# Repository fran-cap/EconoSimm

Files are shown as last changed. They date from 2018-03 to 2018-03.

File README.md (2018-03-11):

# EconoSimm
## A low cost Rom for SE/30 machines and compatables
Simply put this allows for a custom rom to be installed inside of a se/30 to skip things like the built in RAM check.
You can also use any extra space to fit in a small system file.

I've based this off of the work of [Doug Brown](https://www.downtowndougbrown.com/category/mac-rom-hacking/).
And GGlabs [MACSIMM](https://gglabs.us/node/2019).

You can find information about making a rom [here](http://www.bigmessowires.com/mac-rom-inator-ii/) (shoutouts to BMOW)
And how to make a custom disk image [here](http://www.bigmessowires.com/2016/07/22/rom-disk-creation-with-rom-inator-ii/).

The max size of any rom image will depend on the size of the flash chips you use but the max is 4 4mb chips or 2MB in total.
You can split any rom file you make into 4 pieces using the tool of your choice and burn that to each of the 4 chips.

## Note: The pcb has to be 1.2MM thick (approx) or it will not fit into a rom socket!

### You can program the chips individually with a standard flash programmer and a 32 PLCC -> dip adapter
BMOW's programmer may work but I have not tested it.

#### I'm not liable if this damages your Macintosh

## Replaces this:
rom

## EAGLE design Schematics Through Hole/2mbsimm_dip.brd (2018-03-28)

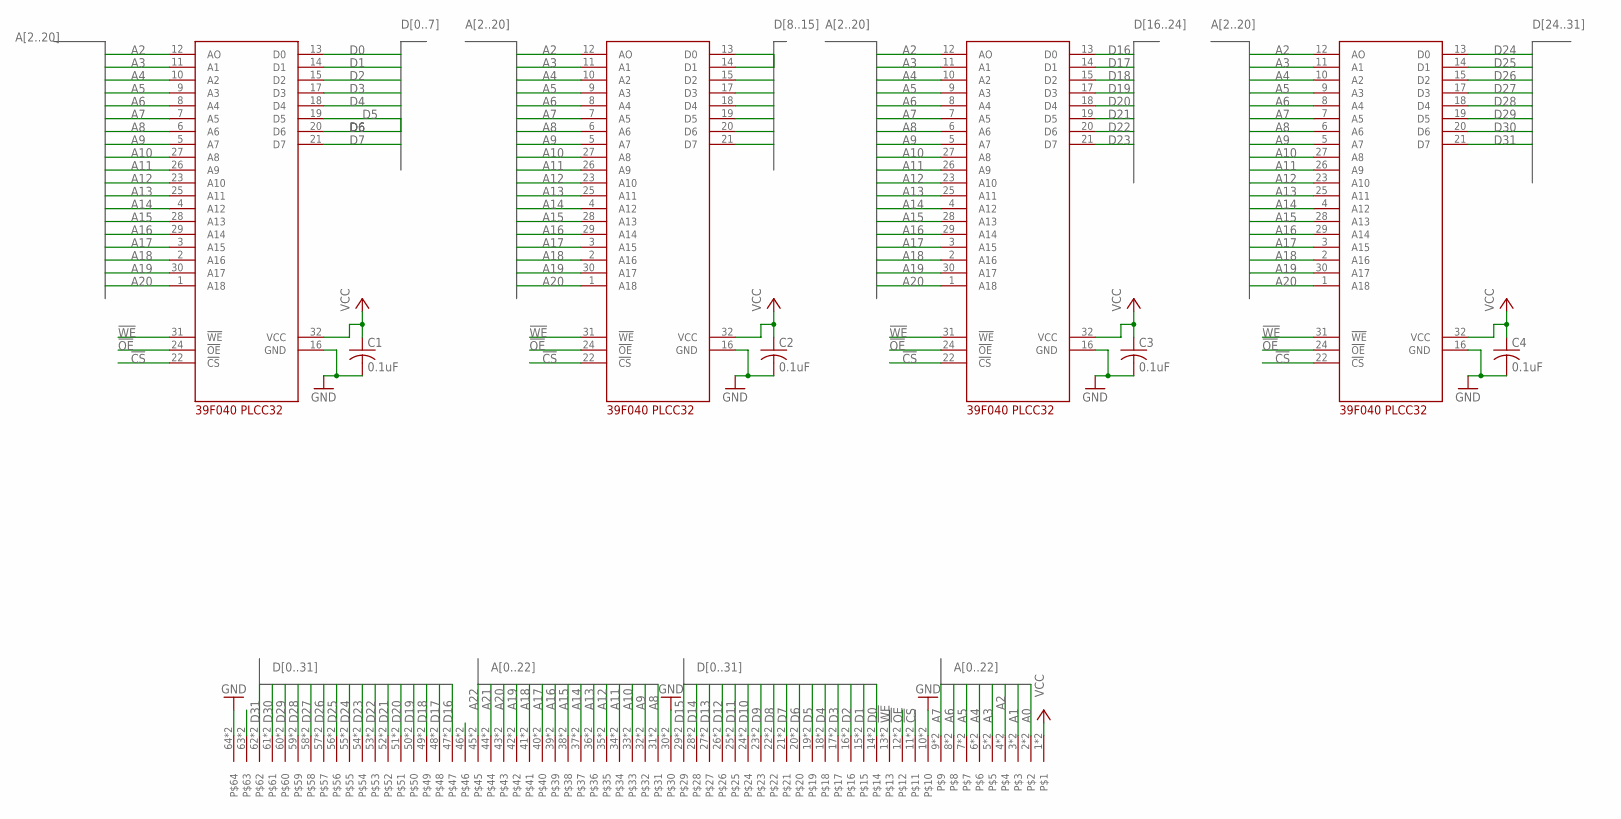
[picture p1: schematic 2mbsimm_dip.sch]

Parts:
C1, C2, C3, C4: 0.1uF; C1206
CON1: MYSIMM; SIMM64L
U$1, U$2, U$3, U$4: 39F040-PLCC-SOCKET-DIP; S32

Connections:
!CS: CON1.11, CON1.75, U$1.22 (!CS), U$2.22 (!CS), U$3.22 (!CS), U$4.22 (!CS)
!OE: CON1.12, CON1.76, U$1.24 (!OE), U$2.24 (!OE), U$3.24 (!OE), U$4.24 (!OE)
!WE: CON1.13, CON1.77, U$1.31 (!WE), U$2.31 (!WE), U$3.31 (!WE), U$4.31 (!WE)
A0: CON1.2, CON1.66
A1: CON1.3, CON1.67
A2: CON1.4, CON1.68, U$1.12 (AO), U$2.12 (AO), U$3.12 (AO), U$4.12 (AO)
A3: CON1.5, CON1.69, U$1.11 (A1), U$2.11 (A1), U$3.11 (A1), U$4.11 (A1)
A4: CON1.6, CON1.70, U$1.10 (A2), U$2.10 (A2), U$3.10 (A2), U$4.10 (A2)
A5: CON1.7, CON1.71, U$1.9 (A3), U$2.9 (A3), U$3.9 (A3), U$4.9 (A3)
A6: CON1.8, CON1.72, U$1.8 (A4), U$2.8 (A4), U$3.8 (A4), U$4.8 (A4)
A7: CON1.9, CON1.73, U$1.7 (A5), U$2.7 (A5), U$3.7 (A5), U$4.7 (A5)
A8: CON1.31, CON1.95, U$1.6 (A6), U$2.6 (A6), U$3.6 (A6), U$4.6 (A6)
A9: CON1.32, CON1.96, U$1.5 (A7), U$2.5 (A7), U$3.5 (A7), U$4.5 (A7)
A10: CON1.33, CON1.97, U$1.27 (A8), U$2.27 (A8), U$3.27 (A8), U$4.27 (A8)
A11: CON1.34, CON1.98, U$1.26 (A9), U$2.26 (A9), U$3.26 (A9), U$4.26 (A9)
A12: CON1.35, CON1.99, U$1.23 (A10), U$2.23 (A10), U$3.23 (A10), U$4.23 (A10)
A13: CON1.36, CON1.100, U$1.25 (A11), U$2.25 (A11), U$3.25 (A11), U$4.25 (A11)
A14: CON1.37, CON1.101, U$1.4 (A12), U$2.4 (A12), U$3.4 (A12), U$4.4 (A12)
A15: CON1.38, CON1.102, U$1.28 (A13), U$2.28 (A13), U$3.28 (A13), U$4.28 (A13)
A16: CON1.39, CON1.103, U$1.29 (A14), U$2.29 (A14), U$3.29 (A14), U$4.29 (A14)
A17: CON1.40, CON1.104, U$1.3 (A15), U$2.3 (A15), U$3.3 (A15), U$4.3 (A15)
A18: CON1.41, CON1.105, U$1.2 (A16), U$2.2 (A16), U$3.2 (A16), U$4.2 (A16)
A19: CON1.42, CON1.106, U$1.30 (A17), U$2.30 (A17), U$3.30 (A17), U$4.30 (A17)
A20: CON1.43, CON1.107, U$1.1 (A18), U$2.1 (A18), U$3.1 (A18), U$4.1 (A18)
A21: CON1.44, CON1.108
A22: CON1.45, CON1.109
D0: CON1.14, CON1.78, U$1.13 (D0)
D1: CON1.15, CON1.79, U$1.14 (D1)
D2: CON1.16, CON1.80, U$1.15 (D2)
D3: CON1.17, CON1.81, U$1.17 (D3)
D4: CON1.18, CON1.82, U$1.18 (D4)
D5: CON1.19, CON1.83, U$1.19 (D5)
D6: CON1.20, CON1.84, U$1.20 (D6)
D7: CON1.21, CON1.85, U$1.21 (D7)
D8: CON1.22, CON1.86, U$2.13 (D0)
D9: CON1.23, CON1.87, U$2.14 (D1)
D10: CON1.24, CON1.88, U$2.15 (D2)
D11: CON1.25, CON1.89, U$2.17 (D3)
D12: CON1.26, CON1.90, U$2.18 (D4)
D13: CON1.27, CON1.91, U$2.19 (D5)
D14: CON1.28, CON1.92, U$2.20 (D6)
D15: CON1.29, CON1.93, U$2.21 (D7)
D16: CON1.47, CON1.111, U$3.13 (D0)
D17: CON1.48, CON1.112, U$3.14 (D1)
D18: CON1.49, CON1.113, U$3.15 (D2)
D19: CON1.50, CON1.114, U$3.17 (D3)
D20: CON1.51, CON1.115, U$3.18 (D4)
D21: CON1.52, CON1.116, U$3.19 (D5)
D22: CON1.53, CON1.117, U$3.20 (D6)
D23: CON1.54, CON1.118, U$3.21 (D7)
D24: CON1.55, CON1.119, U$4.13 (D0)
D25: CON1.56, CON1.120, U$4.14 (D1)
D26: CON1.57, CON1.121, U$4.15 (D2)
D27: CON1.58, CON1.122, U$4.17 (D3)
D28: CON1.59, CON1.123, U$4.18 (D4)
D29: CON1.60, CON1.124, U$4.19 (D5)
D30: CON1.61, CON1.125, U$4.20 (D6)
D31: CON1.62, CON1.126, U$4.21 (D7)
GND: C1.2, C2.2, C3.2, C4.2, CON1.10, CON1.30, CON1.64, CON1.74, CON1.94, CON1.128, U$1.16 (GND), U$2.16 (GND), U$3.16 (GND), U$4.16 (GND)
unnamed: CON1.46, CON1.110
UNUSED3: CON1.63, CON1.127
VCC: C1.1, C2.1, C3.1, C4.1, CON1.1, CON1.65, U$1.32 (VCC), U$2.32 (VCC), U$3.32 (VCC), U$4.32 (VCC)

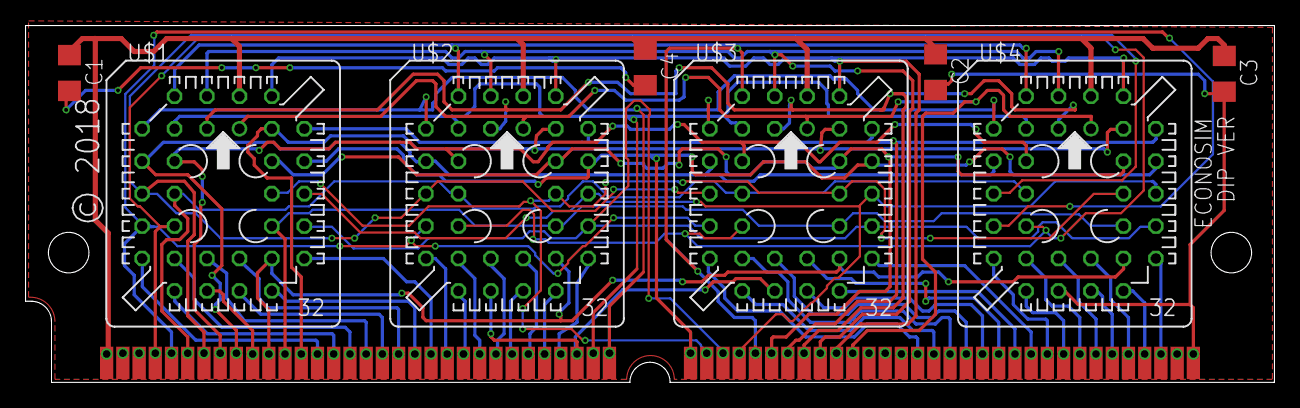
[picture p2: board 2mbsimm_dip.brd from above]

Board: 2 copper layers, 97.8 x 27.9 mm, 9 parts (0 on the bottom side), 62 nets.

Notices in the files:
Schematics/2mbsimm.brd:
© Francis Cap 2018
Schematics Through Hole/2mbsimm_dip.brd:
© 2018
